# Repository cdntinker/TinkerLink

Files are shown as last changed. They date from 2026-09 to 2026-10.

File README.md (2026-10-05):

# Theory of operation:
* Power source is connected to USB1
  * can be populated with USB-C female or USB-A male
* USB2 can have its power turned on/off by the MCU using io12
  * can be populated with USB-C male or female
* D+ & D1, of course, pass right through
* When using USB-C on both ends, CC1 & CC2 are pased through (but swapped) and should allow for USB-PD capabilities
  * Also: R9 & R10 are there to add 5k1 resistors if needed.
    * Now the ESP handles inserting them via io2...
* LED1 is an RGB addressible LED (on io14) for status indication
  * RGBW now... Austin's fault... Blame Austin
* SW1 is on io13 of the MCU and can be used for local control

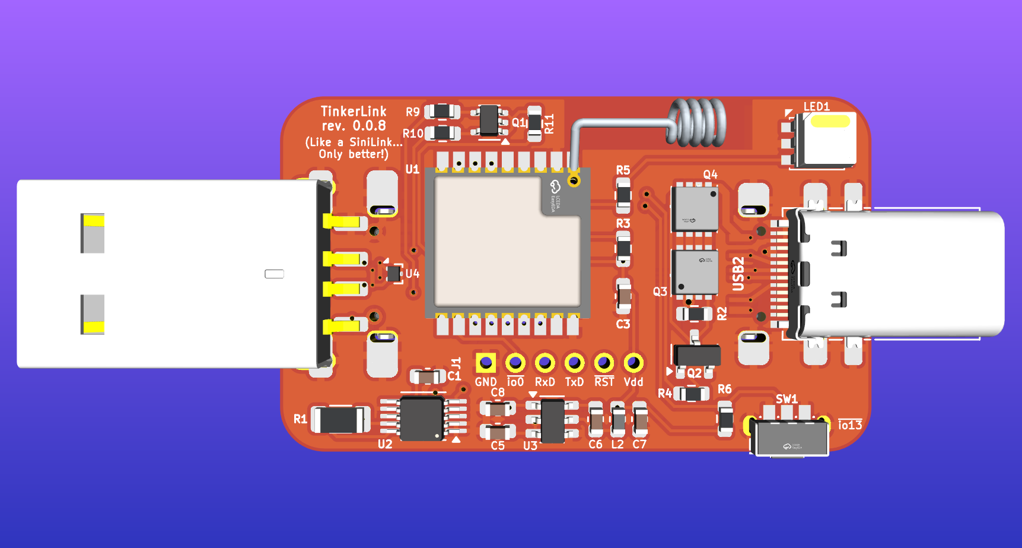
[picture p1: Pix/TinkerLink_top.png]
A 3D render of the device


# Power Monitoring thoughts:
* INA chip selection
* The following are all drop-in replacements for each other...
  * INA228 (Current chip in the design)
    * very expensive
    * 625uA resoluation
  * INA237
    * 1/3 the price
    * 800uA resoluation
  * INA226
    * under a buck...
    * 1.5mA resoluation

# Firmware:
* Yet to be developped...
* Might work with TasmOTA like the original SiniLink could

# Notes:
Thanks to DJ_Dichotomy in the SuperHouseTV Discord for the antenna model...

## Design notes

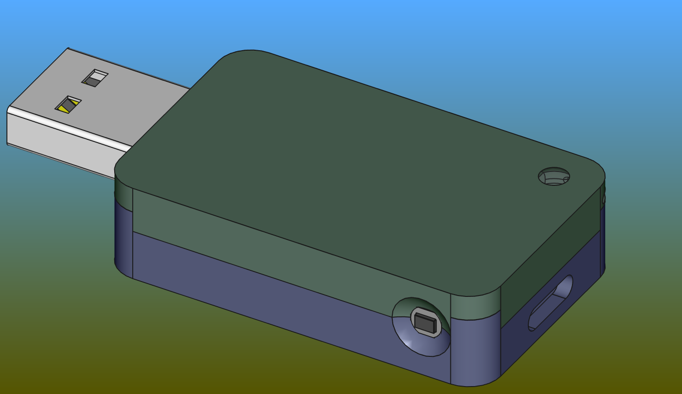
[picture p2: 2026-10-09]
3D/Am-Cf.png

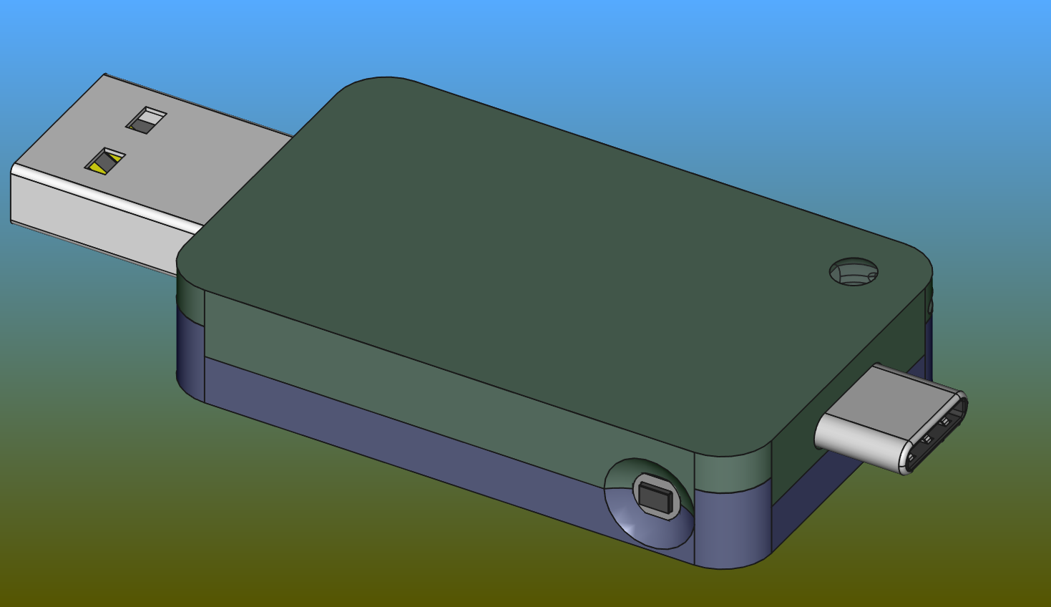
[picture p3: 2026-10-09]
3D/Am-Cm.png

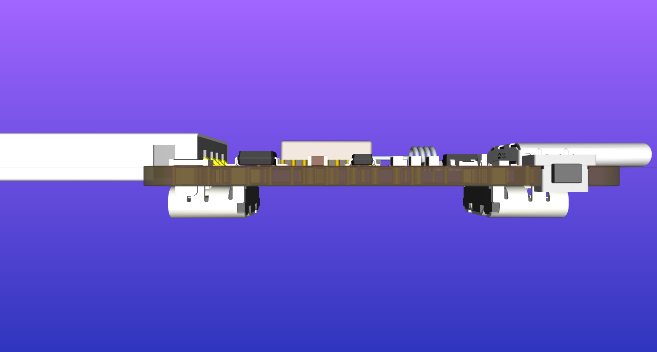
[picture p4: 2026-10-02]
Pix/TinkerLink_edg.png

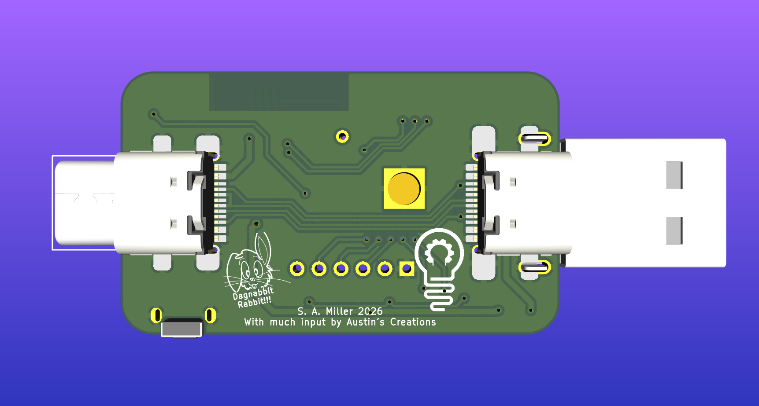
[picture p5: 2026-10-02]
Pix/TinkerLink_btm.png

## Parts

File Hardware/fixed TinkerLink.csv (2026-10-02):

Reference | Qty | Value | LCSC Part | LCSC Part2 | DNP | Exclude from BOM | Exclude from Board | Footprint
C1,C6 | 2 | 100nf | C14663 |  |  |  |  | Capacitor_SMD:C_0603_1608Metric
C3,C5 | 2 | 10uf | C19702 |  |  |  |  | Capacitor_SMD:C_0603_1608Metric
C7,C8 | 2 | 22uF | C20416425 |  |  |  |  | Capacitor_SMD:C_0603_1608Metric
L2 | 1 | 3.9uH | C252079 |  |  |  |  | Inductor_SMD:L_0603_1608Metric
LED1 | 1 | SK6812MINIRGBW-WS-P6-A | C7423106 |  |  |  |  | LCSCfootprints:LED-SMD_6P-L3.5-W3.5_SK6812MINIRGBW-WS-P6-A
Q1 | 1 | DMN32D2LDF | C672154 |  |  |  |  | Package_TO_SOT_SMD:SOT-353_SC-70-5
Q2 | 1 | MMBT2222A | C916372 |  |  |  |  | Package_TO_SOT_SMD:SOT-23
Q3,Q4 | 2 | SQS411ENW-T1_GE3 | C3279469 |  |  |  |  | LCSCfootprints:POWERPAK-1212-8_L3.1-W3.1-P0.65-LS3.3-BL
R1 | 1 | 2mR 1w | C710257 |  |  |  |  | Resistor_SMD:R_1206_3216Metric
R2,R3,R6 | 3 | 10K | C98220 |  |  |  |  | Resistor_SMD:R_0603_1608Metric
R4,R11 | 2 | 1K | C22548 |  |  |  |  | Resistor_SMD:R_0603_1608Metric
R5 | 1 | 470R | C114433 |  |  |  |  | Resistor_SMD:R_0603_1608Metric
R9,R10 | 2 | 5k1 | C23186 |  |  |  |  | Resistor_SMD:R_0603_1608Metric
SW1 | 1 | TS-061D-250D4-P | C53207951 |  |  |  |  | LCSCfootprints:SW-SMD_K2-1847DT-A4SA-01
U1 | 1 | ESP-01F-2M | C2764054 |  |  |  |  | LCSCfootprints:ESP-01F
U2 | 1 | INA228 | C2887910 |  |  |  |  | Package_SO:VSSOP-10_3x3mm_P0.5mm
U3 | 1 | AP63203WU | C780769 |  |  |  |  | Package_TO_SOT_SMD:TSOT-23-6
U4 | 1 | TPD2EUSB30A | C3011197 |  |  |  |  | Package_TO_SOT_SMD:Texas_DRT-3
USB1 | 1 | USB-A-USB-C | C720521 |  |  |  |  | TINKERfootprints:USB-A-USB-C
USB2 | 1 | USB-C-Hermaphrodite | C5370430 |  |  |  |  | TINKERfootprints:USB_C_Hermaphrodite
USBb | 2 | USB-C alternates | C2765186

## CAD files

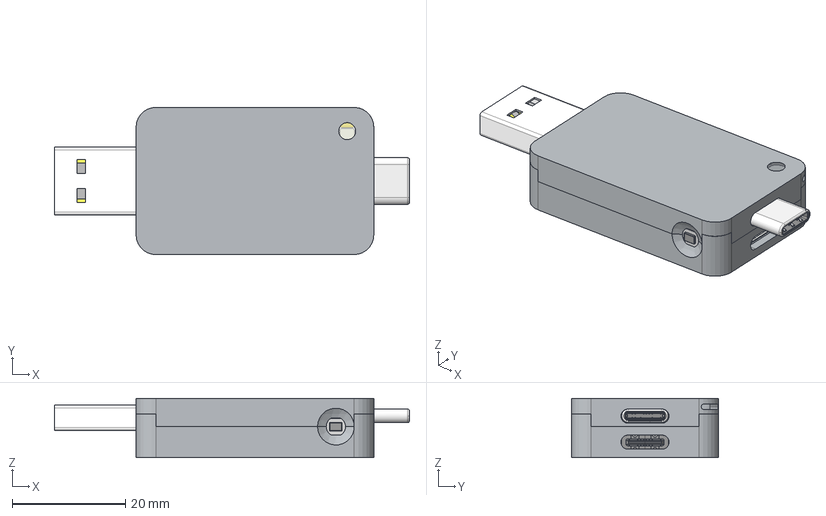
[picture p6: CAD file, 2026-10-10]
3D/TinkerLink case design tweaking.step
62.7 x 26.0 x 10.5 mm
Da Bottom ()
Da Top ()
LightPipe009
TinkerLink_PCB001
LED-SMD_6P-L3.5-W3.5_SK6812MINIRGBW-WS-P6-A002
SW-SMD_K2-1847DT-A4SA-003
USB-A-SMD in001
USB-C-SMD out001
USB_C_Receptacle in001
USB_C_Receptacleout001

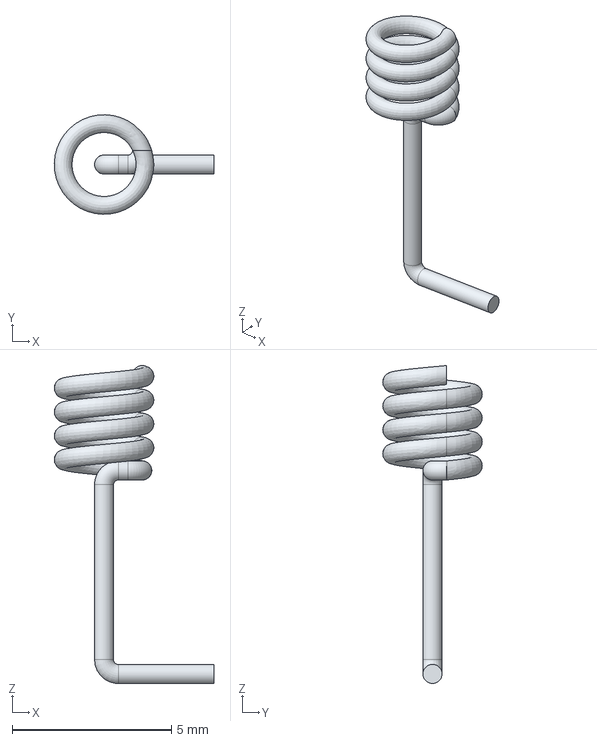
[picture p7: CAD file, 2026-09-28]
Hardware/KiCAD_Customs/Antenna-thingy-bent.step
5.02 x 3.13 x 10.00 mm

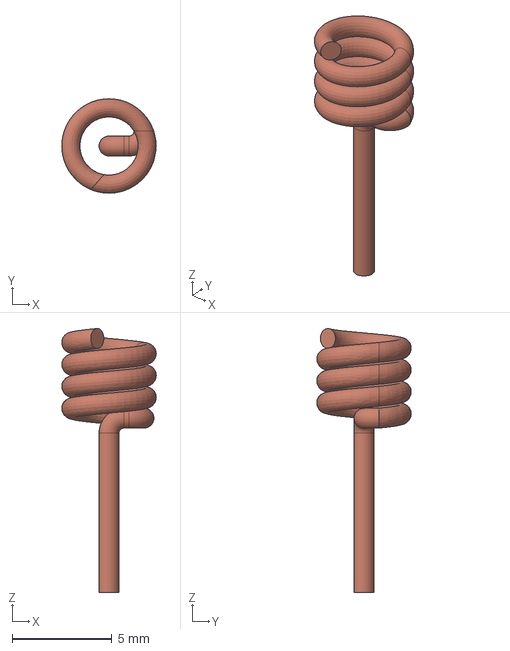
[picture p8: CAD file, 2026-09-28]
Hardware/KiCAD_Customs/C2764054/Antenna-thingy-Body.step
4.74 x 4.74 x 13.2 mm

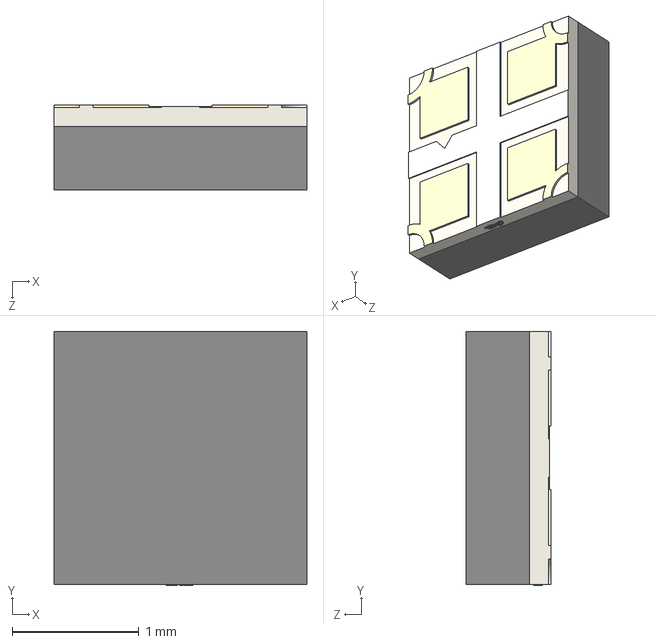
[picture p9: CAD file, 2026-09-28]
Hardware/KiCAD_Customs/C2909058/LED-SMD_4P-L2.0-W2.0-BR.step
2.00 x 2.01 x 0.67 mm

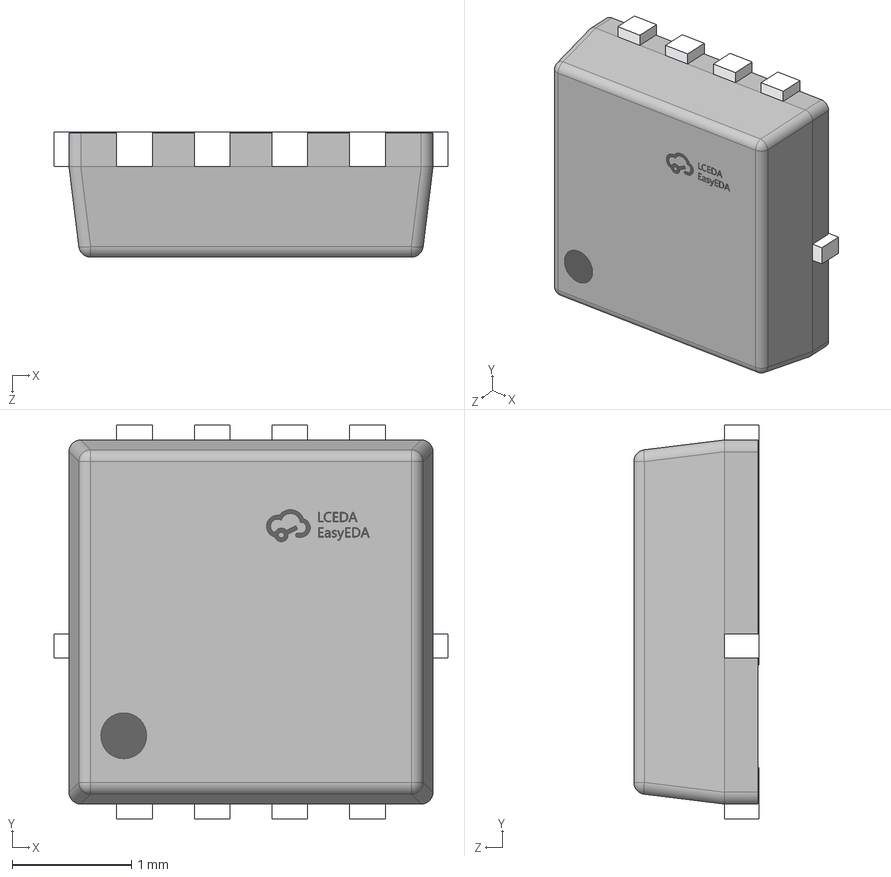
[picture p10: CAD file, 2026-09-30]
Hardware/KiCAD_Customs/C3279469/POWERPAK-1212-8_L3.1-W3.1-P0.65-LS3.3-BL.step
3.30 x 3.30 x 1.05 mm

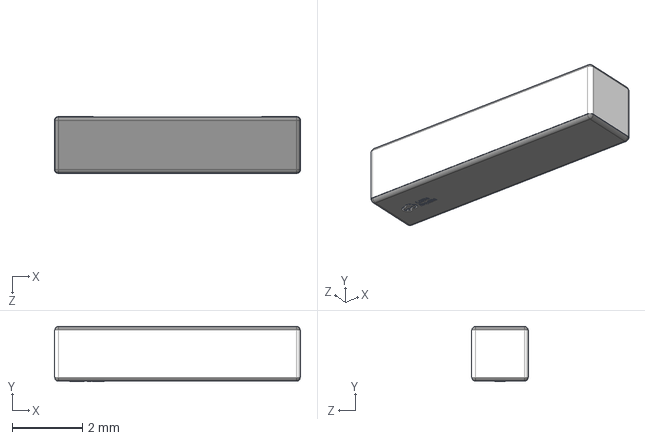
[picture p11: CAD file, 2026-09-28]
Hardware/KiCAD_Customs/C515701/ANT-SMD_L7.0-W1.6.step
7.02 x 1.57 x 1.62 mm

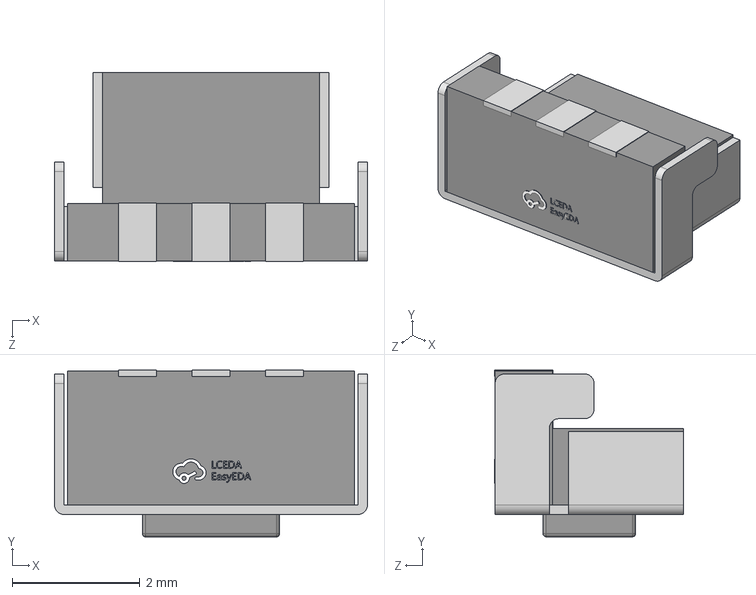
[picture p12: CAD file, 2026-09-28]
Hardware/KiCAD_Customs/C53207951/SW-SMD_K2-1847DT-A4SA-01.step
4.90 x 2.61 x 2.96 mm

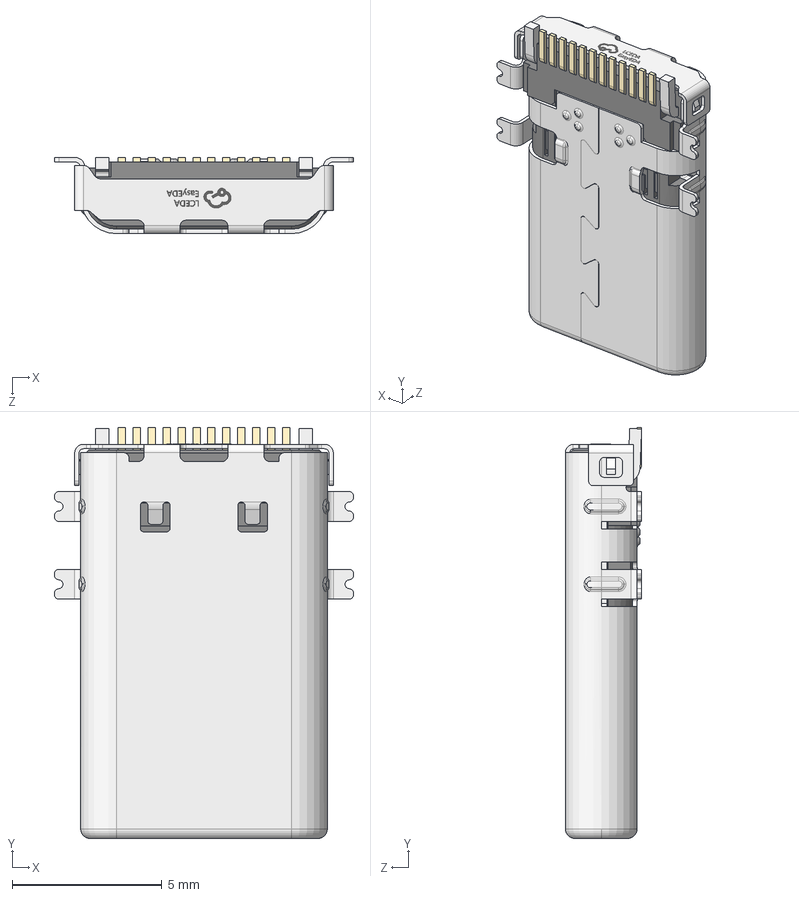
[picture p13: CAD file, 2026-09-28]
Hardware/KiCAD_Customs/C5370430/USB-C-SMD_TYPE-C-31-G-10.step
10.0 x 13.7 x 2.55 mm

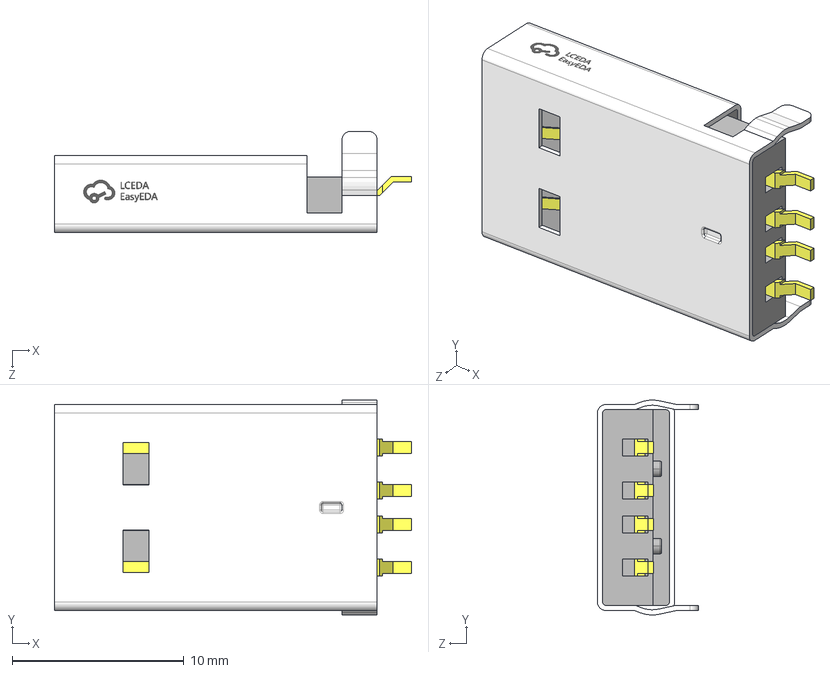
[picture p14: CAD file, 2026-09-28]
Hardware/KiCAD_Customs/C720521/USB-A-SMD_USB-212-BCW.step
20.8 x 12.5 x 5.90 mm

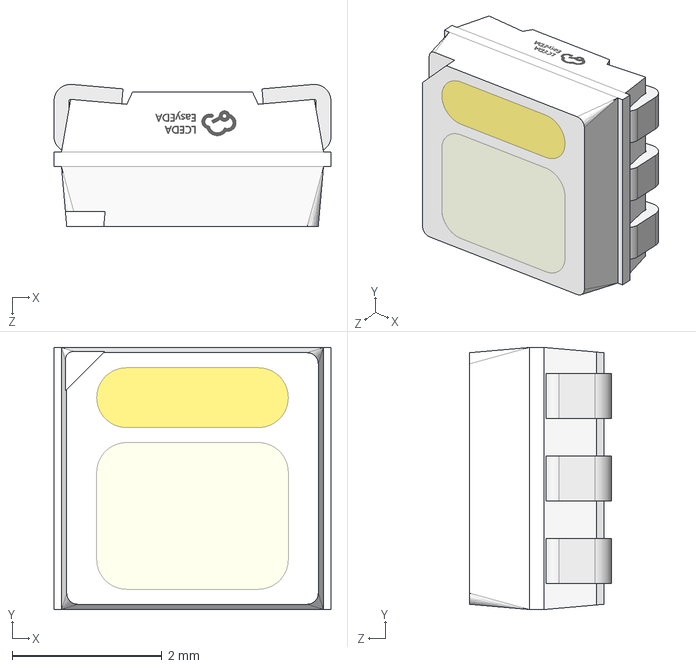
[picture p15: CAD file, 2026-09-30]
Hardware/KiCAD_Customs/C7423106/LED-SMD_6P-L3.5-W3.5_SK6812MINIRGBW-WS-P6-A.step
3.70 x 3.50 x 1.90 mm

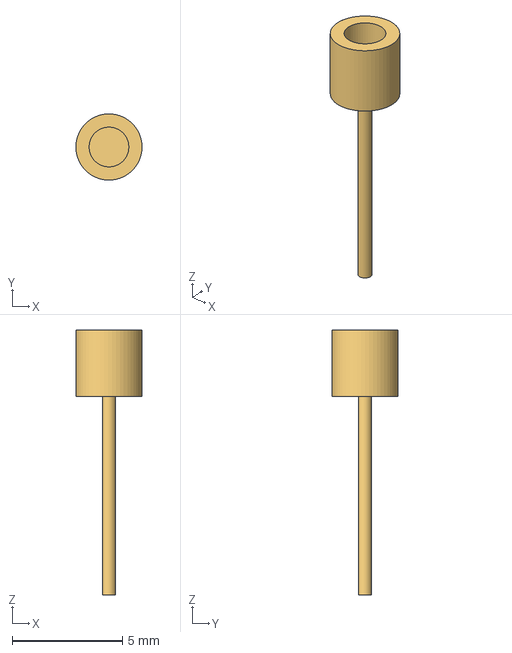
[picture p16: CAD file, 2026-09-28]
Hardware/KiCAD_Customs/antenna.step
3.00 x 3.00 x 12.0 mm

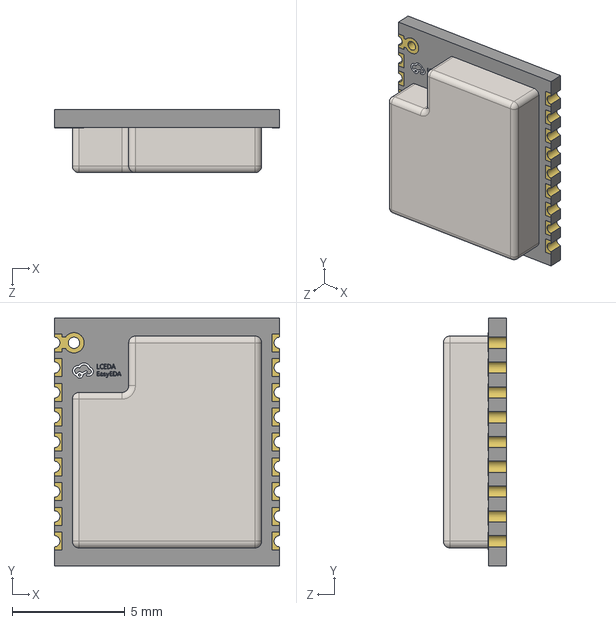
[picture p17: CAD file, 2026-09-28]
Hardware/KiCAD_Customs/C2764054/WIFIM-SMD_ESP-01F-2M.step
10.0 x 11.0 x 2.81 mm

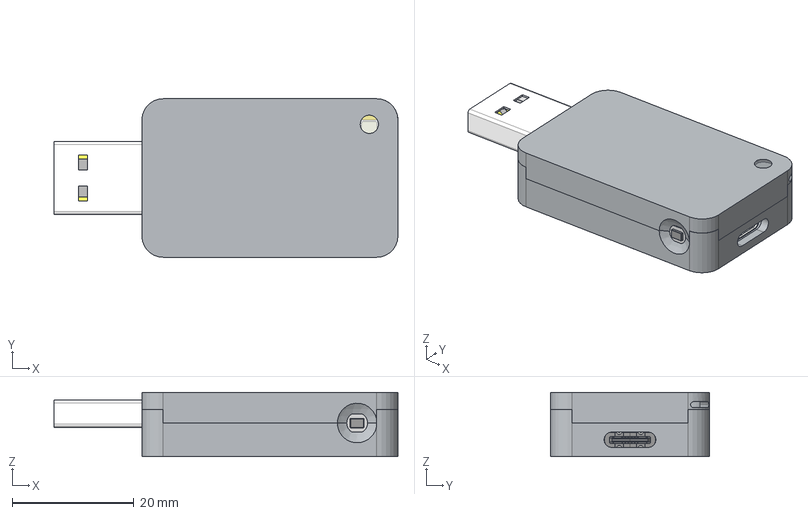
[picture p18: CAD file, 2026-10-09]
3D/Am-Cf.step
56.4 x 26.0 x 10.5 mm
Da Bottom ()001
Da Top ()001
LightPipe011
TinkerLink_PCB003
LED-SMD_6P-L3.5-W3.5_SK6812MINIRGBW-WS-P6-A004
SW-SMD_K2-1847DT-A4SA-005
USB-A-SMD in003
USB_C_Receptacleout003

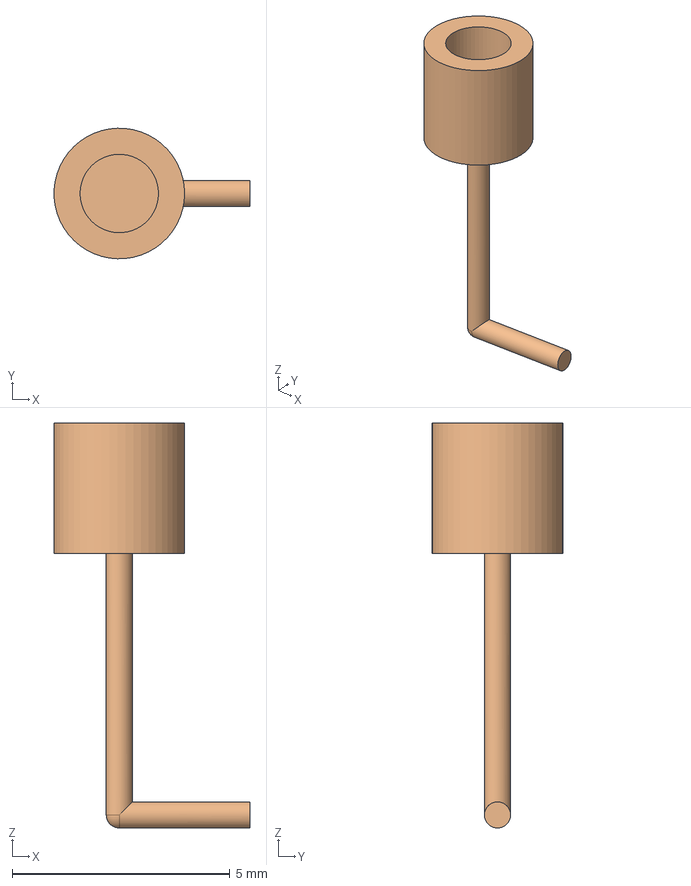
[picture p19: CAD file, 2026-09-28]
Hardware/KiCAD_Customs/antenna B.step
4.50 x 3.00 x 9.30 mm

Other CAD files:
3D/Generic.step
Hardware/KiCAD_Customs/Antenna-thingy.FCStd
Hardware/KiCAD_Customs/C2764054/Antenna-thingy.step
3D/TinkerLink case design.FCStd
3D/Am-Cm.step
3D/Cf-Cf.step
3D/Cf-Cm.step
3D/TinkerLink case design tweaking.FCStd
Hardware/KiCAD_Customs/Antenna-thingy-straight.step
Hardware/KiCAD_Customs/antenna.FCStd

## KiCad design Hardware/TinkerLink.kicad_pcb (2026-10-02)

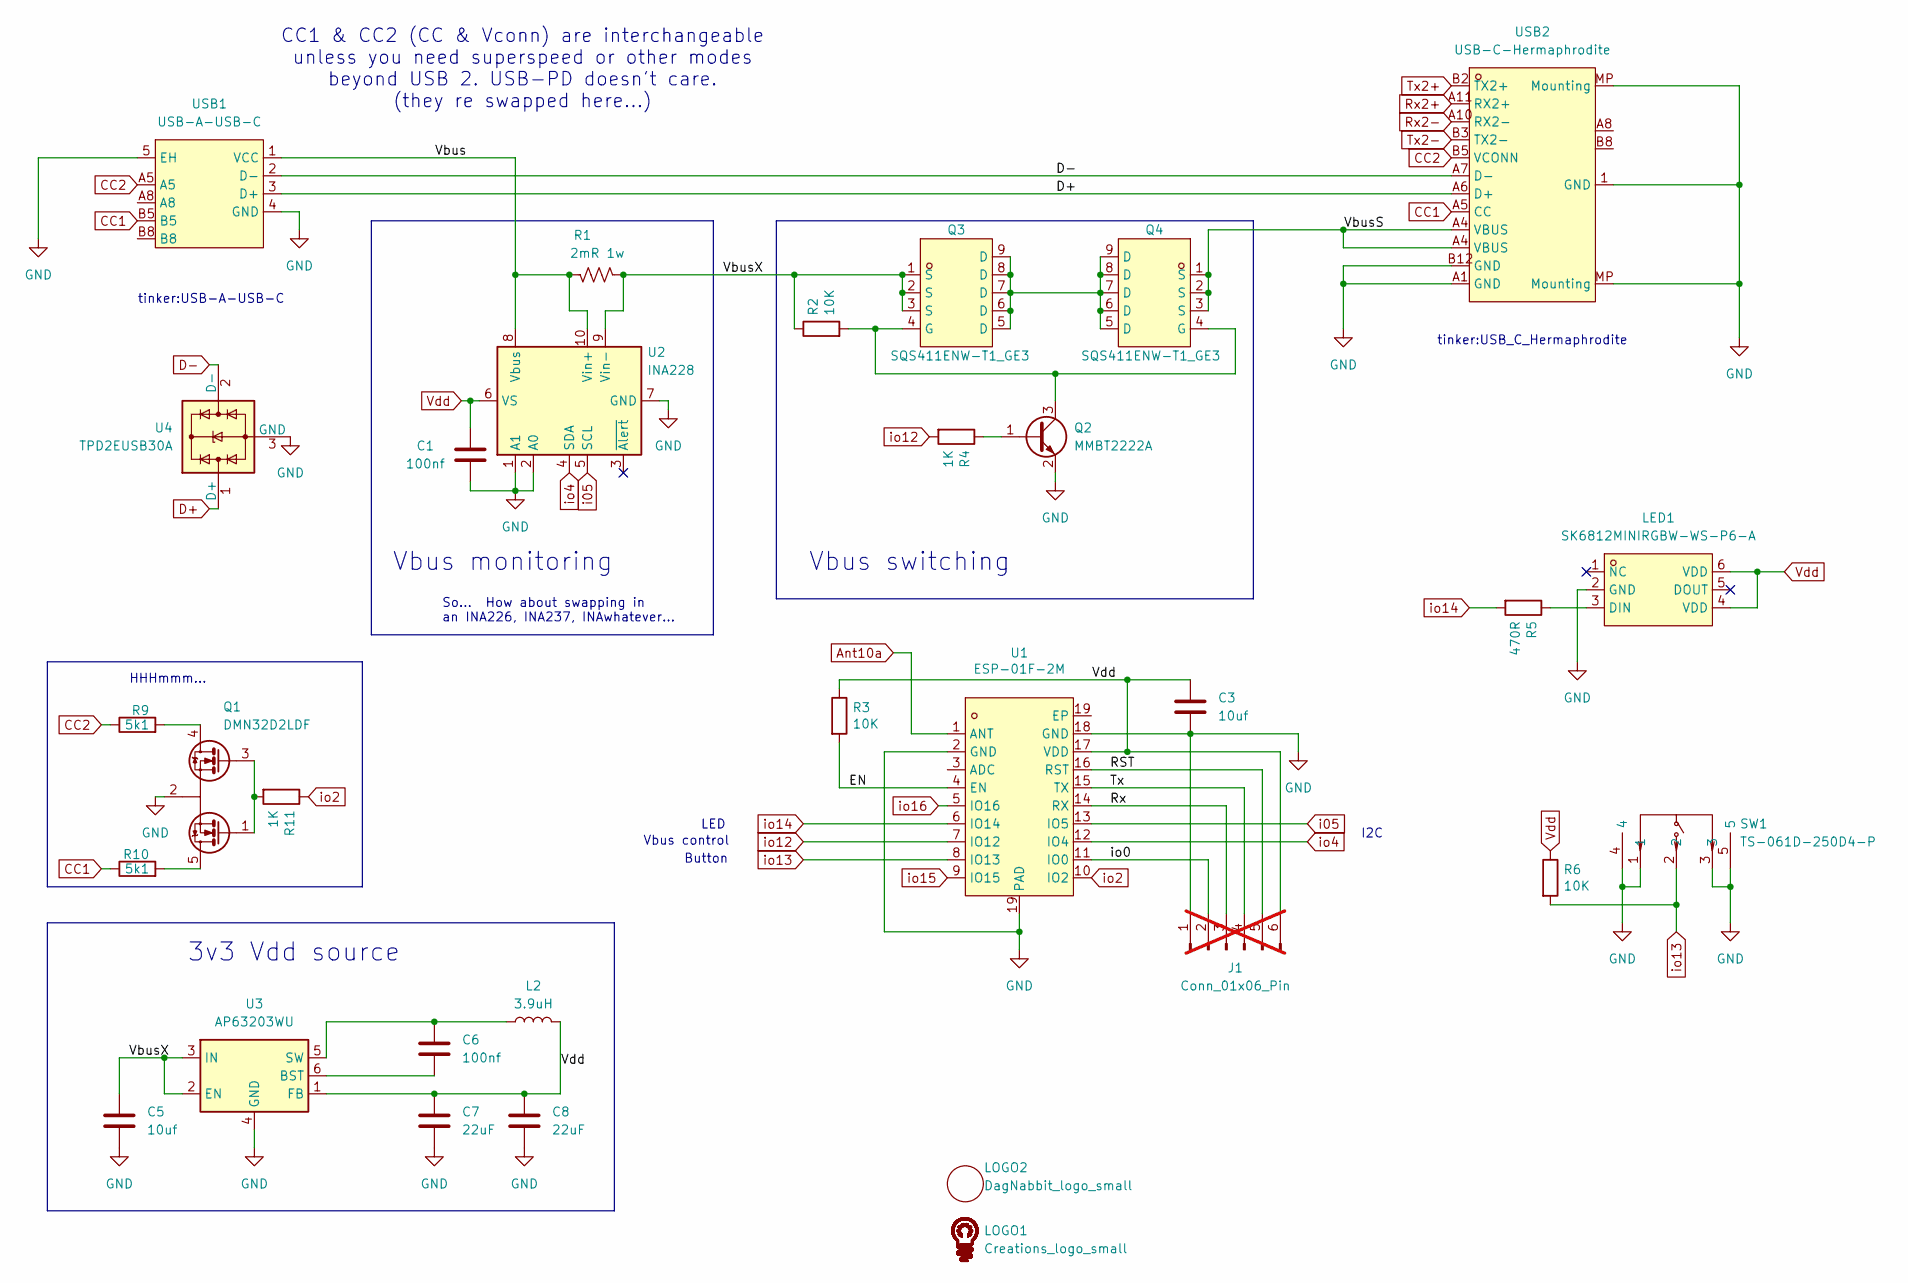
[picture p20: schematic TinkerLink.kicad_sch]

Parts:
C1: 100nf; C_0603_1608Metric; LCSC Part C14663
C3, C5: 10uf; C_0603_1608Metric; LCSC Part C19702
C6: 100nf; C_0603_1608Metric
C7, C8: 22uF; C_0603_1608Metric; LCSC Part C20416425
J1: Conn_01x06_Pin; ProgHeader_1x06_P2.00mm; not fitted
L2: 3.9uH; L_0603_1608Metric; LCSC Part C252079
LED1: SK6812MINIRGBW-WS-P6-A; LED-SMD_6P-L3.5-W3.5_SK6812MINIRGBW-WS-P6-A; MPN SK6812MINIRGBW-WS-P6-A; LCSC Part C7423106
LOGO1: Creations_logo_small; Creations logo small
LOGO2: DagNabbit_logo_small; DagNabbit
Q1: DMN32D2LDF; SOT-353_SC-70-5; LCSC Part C672154
Q2: MMBT2222A; SOT-23; LCSC Part C916372
Q3, Q4: SQS411ENW-T1_GE3; POWERPAK-1212-8_L3.1-W3.1-P0.65-LS3.3-BL; MPN SQS411ENW-T1_GE3; LCSC Part C3279469
R1: 2mR 1w; R_1206_3216Metric; LCSC Part C710257
R2, R3, R6: 10K; R_0603_1608Metric; LCSC Part C98220
R4, R11: 1K; R_0603_1608Metric; LCSC Part C22548
R5: 470R; R_0603_1608Metric; LCSC Part C114433
R9, R10: 5k1; R_0603_1608Metric; LCSC Part C23186
SW1: TS-061D-250D4-P; SW-SMD_K2-1847DT-A4SA-01; MPN TS-061D-250D4-P; LCSC Part C53207951
U1: ESP-01F-2M; ESP-01F; MPN ESP-01F-2M; LCSC Part C2764054
U2: INA228; VSSOP-10_3x3mm_P0.5mm; LCSC Part C2887910
U3: AP63203WU; TSOT-23-6; LCSC Part C780769
U4: TPD2EUSB30A; Texas_DRT-3; LCSC Part C3011197
USB1: USB-A-USB-C; MPN USB-212-BCW; LCSC Part C720521
USB2: USB-C-Hermaphrodite; USB_C_Hermaphrodite; MPN TYPE-C-31-G-10; LCSC Part C5370430

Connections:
/EN: R3.2, U1.4 (EN)
/RST: J1.5, U1.16 (RST)
/Rx: J1.3, U1.14 (RX)
/Tx: J1.4, U1.15 (TX)
/Vbus: R1.2, U2.8 (Vbus), U2.10 (Vin+), USB1.1 (VCC)
/VbusS: Q4.1 (S), Q4.2 (S), Q4.3 (S), USB2.A4 (VBUS)
/VbusX: C5.1, Q3.1 (S), Q3.2 (S), Q3.3 (S), R1.1, R2.1, U2.9 (Vin-), U3.2 (EN), U3.3 (IN)
/io0: J1.2, U1.11 (IO0)
Ant10a: U1.1 (ANT)
CC1: R10.1, USB1.B5, USB2.A5 (CC)
CC2: R9.1, USB1.A5, USB2.B5 (VCONN)
D+: U4.1 (D+), USB1.3 (D+), USB2.A6 (D+)
D-: U4.2 (D-), USB1.2 (D-), USB2.A7 (D-)
GND: C1.2, C3.2, C5.2, C7.2, C8.2, J1.1, LED1.2 (GND), Q1.2 (S), Q2.2 (E), SW1.1, SW1.3, SW1.4, SW1.5, U1.2 (GND), U1.18 (GND), U1.19 (PAD), U2.1 (A1), U2.2 (A0), U2.7 (GND), U3.4 (GND), U4.3 (GND), USB1.4 (GND), USB1.5 (EH), USB2.1 (GND), USB2.A1 (GND), USB2.B12 (GND), USB2.MP (Mounting)
unnamed: LED1.3 (DIN), R5.1
unnamed: Q1.5 (D1), R10.2
unnamed: Q1.4 (D2), R9.2
unnamed: Q1.1 (G1), Q1.3 (G2), R11.2
unnamed: Q2.1 (B), R4.1
unnamed: Q2.3 (C), Q3.4 (G), Q4.4 (G), R2.2
unnamed: Q3.5 (D), Q3.6 (D), Q3.7 (D), Q3.8 (D), Q3.9 (D), Q4.5 (D), Q4.6 (D), Q4.7 (D), Q4.8 (D), Q4.9 (D)
unnamed: C6.2, U3.6 (BST)
unnamed: C6.1, L2.1, U3.5 (SW)
Rx2+: USB2.A11 (RX2+)
Rx2-: USB2.A10 (RX2-)
Tx2+: USB2.B2 (TX2+)
Tx2-: USB2.B3 (TX2-)
Vdd: C1.1, C3.1, C7.1, C8.1, J1.6, L2.2, LED1.4 (VDD), LED1.6 (VDD), R3.1, R6.1, U1.17 (VDD), U2.6 (VS), U3.1 (FB)
i05: U1.13 (IO5), U2.5 (SCL)
io2: R11.1, U1.10 (IO2)
io4: U1.12 (IO4), U2.4 (SDA)
io12: R4.2, U1.7 (IO12)
io13: R6.2, SW1.2, U1.8 (IO13)
io14: R5.2, U1.6 (IO14)
io15: U1.9 (IO15)
io16: U1.5 (IO16)

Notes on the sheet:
HHHmmm...
tinker:USB-A-USB-C
Button
LED
So... How about swapping in an INA226, INA237, INAwhatever...
CC1 & CC2 (CC & Vconn) are interchangeable unless you need superspeed or other modes beyond USB 2. USB-PD doesn't care. (they re swapped here...)
Vbus monitoring
Vbus switching
3v3 Vdd source
tinker:USB_C_Hermaphrodite
I2C
Vbus control

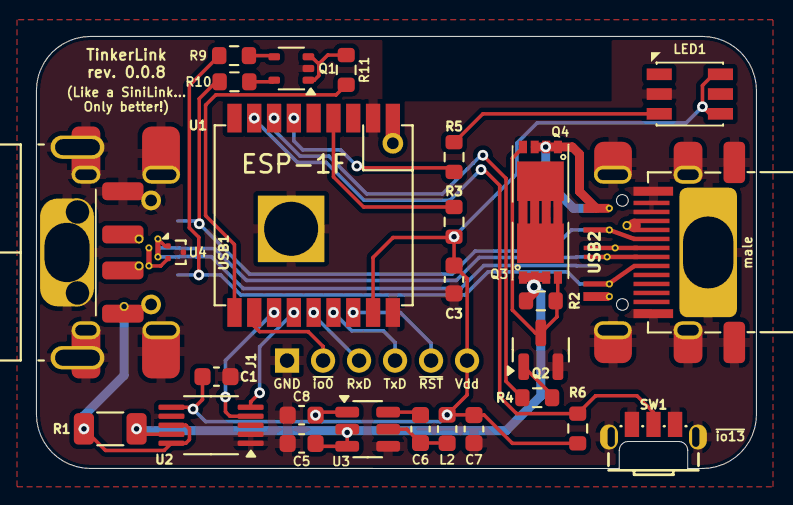
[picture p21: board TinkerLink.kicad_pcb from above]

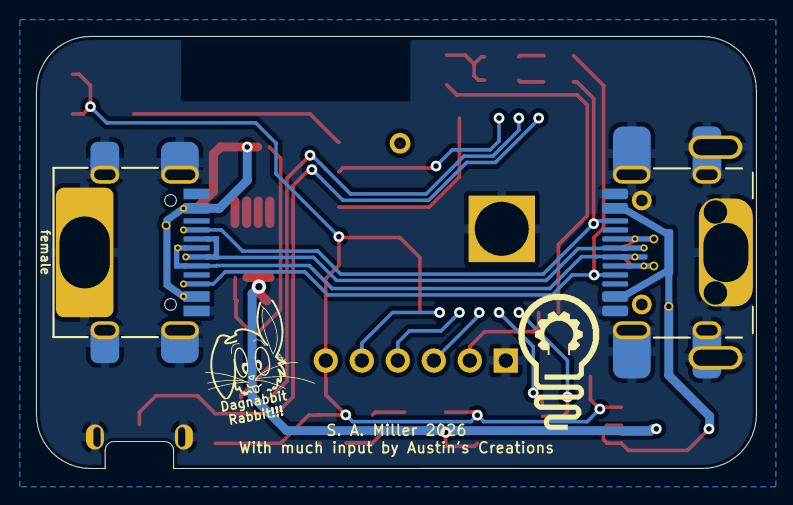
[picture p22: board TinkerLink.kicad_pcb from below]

Board: 2 copper layers, 40.0 x 24.0 mm, 31 parts (2 on the bottom side), 29 nets.

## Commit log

2026-09-28 Delete poopy directory
    was leftover poop
    [Rabbit Poop.kicad_pcb, Rabbit Poop.kicad_sch, Rabbit Poop.step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]
2026-09-28 Layout squeezed to the right
    [TinkerLink.kicad_pcb]
2026-09-28 fiddlin' with silscreen
    [TinkerLink.kicad_pcb]
2026-09-29 Bloody Rabbit Hole Sub-Basement!
    [TinkerLink.kicad_pcb, TinkerLink.kicad_sch]
2026-09-29 Tweakin' (NOT twerkin') coz Austin hasn't admitted to doin' anything yet...
    [TinkerLink.kicad_pcb]
2026-09-29 tweak tweak tweak
    [TinkerLink.kicad_pcb]
2026-09-29 aaannnddd tweakin'...
    [TinkerLink.kicad_pcb, TinkerLink.kicad_sch]
2026-09-29 USB1 footprint improvement
    [TinkerLink.kicad_pcb]
2026-09-29 More USB connector tweaks
    [TinkerLink.kicad_pcb]
2026-09-29 Possible replacement 3v3 source
    [TinkerLink.kicad_sch]
2026-09-30 new 3v3 in place(ish)
    [TinkerLink.kicad_pcb, TinkerLink.kicad_sch]
2026-09-30 Austin instigated FET change
    [POWERPAK-1212-8_L3.1-W3.1-P0.65-LS3.3-BL.step, TinkerLink.kicad_pcb, TinkerLink.kicad_sch]
2026-09-30 Dual FETs
    [TinkerLink.kicad_pcb, TinkerLink.kicad_sch]
2026-09-30 upgrades
    adds ina228 and 3535 rgbw sk6812 LED
    [TinkerLink.kicad_pcb, TinkerLink.kicad_sch]
2026-09-30 add AC logo
    [TinkerLink.kicad_pcb, TinkerLink.kicad_sch]
2026-09-30 first tweaks post Austin...
    [TinkerLink.kicad_pcb, TinkerLink.kicad_sch]
2026-09-30 Added TPD2EUSB30A to D+/D- for ESD protection
    [TinkerLink.kicad_pcb, TinkerLink.kicad_sch]
2026-10-01 Not twerks... tweaks!
    [TinkerLink.kicad_pcb, TinkerLink.kicad_sch]
2026-10-01 can't... stop... tweakin'...
    [TinkerLink.kicad_pcb, TinkerLink.kicad_sch]
2026-10-01 BOM, Notes, ...
    [TinkerLink.csv, TinkerLink.kicad_sch]
2026-10-01 smaller AC logo
    [TinkerLink.kicad_pcb, TinkerLink.kicad_sch]
2026-10-02 Minor tweaks & notes about INA chips...
    [TinkerLink.csv]
2026-10-02 Nasty initial CC1/2 resistors solution
    [TinkerLink.kicad_pcb, TinkerLink.kicad_sch]
2026-10-02 workin on some included libs...
    [TinkerLink.csv, TinkerLink.kicad_pcb, TinkerLink.kicad_sch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]
2026-10-02 CC1&2 resistors now controllable
    [TinkerLink.kicad_pcb, TinkerLink.kicad_sch]
2026-10-02 i THINK I have the repo libs workin'
    [TinkerLink.kicad_pcb, TinkerLink.kicad_sch]
2026-10-02 Starting to prep for publication
    [ANT-SMD_L7.0-W1.6.step, Antenna-thingy-Body.step, Antenna-thingy-bent.step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]
2026-10-03 Very first case design step
    [TinkerLink case design.FCStd]
2026-10-04 a bit o' fiddlin' with the case design
    [TinkerLink case design.FCStd]
2026-10-04 More case fiddlin'
    [TinkerLink case design.FCStd]
2026-10-04 Bit more fiddlin'
    [TinkerLink case design.FCStd]
2026-10-05 can't... stop... fiddlin'...
    [TinkerLink case design.FCStd]
2026-10-05 fiddlin' gone crazy...
    [Case Btm Cut (male connectors only).step, Case Btm Cut.step, Case Top Cut (female connectors only).step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]
2026-10-07 Case tweaks dun got fiddled...
    [Case Btm Cut (Am-Cf).step, Case Btm Cut (Am-Cm).step, Case Btm Cut (Cf-Cf).step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]
2026-10-07 Added possible closure clips
    [TinkerLink case design (with clips).step, TinkerLink case design Btm (with clips).step, TinkerLink case design Top (with clips).step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]
2026-10-08 Better closure clips?
    [TinkerLink case design (with NEW clips).step, TinkerLink case design.FCStd]
2026-10-09 and maybe a slightly better lightpipe in that particular group...
    [TinkerLink case design.FCStd]
2026-10-09 Quite possibly approaching final case design...
    [Am-Cf.step, Am-Cm.step, Case Btm Cut (Am-Cf).step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]
2026-10-09 + a "generic" STEP file
    [Generic.step]
2026-10-10 dang... tweakin again...
    [TinkerLink case design tweaking.FCStd, TinkerLink case design tweaking.step]
